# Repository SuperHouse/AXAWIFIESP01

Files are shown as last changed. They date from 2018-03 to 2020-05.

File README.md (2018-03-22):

AXA Electric Window Motor WiFi Controller (ESP-01)
===================================================
Copyright 2017 SuperHouse Automation Pty Ltd  www.superhouse.tv  

Add-in board for AXA domestic electric window mechanisms, to fit into
the battery compartment in place of the AA cells that are normally
installed. Uses an ESP8266 to connect to WiFi, and controls the AXA
window motor using LINbus.

More information is available on the project page at:

  http://www.superhouse.tv/axawifi

INSTALLATION
------------
The design is saved as an EAGLE project. EAGLE PCB design software is
available from www.cadsoftusa.com free for non-commercial use. To use
this project download it and place the directory containing these files
into the "eagle" directory on your computer. Then open EAGLE and
navigate to the projects listing.

DISTRIBUTION
------------
The specific terms of distribution of this project are governed by the
license referenced below.

LICENSE
-------
Licensed under the TAPR Open Hardware License (www.tapr.org/OHL).
The "license" folder within this repository also contains a copy of
this license in plain text format.

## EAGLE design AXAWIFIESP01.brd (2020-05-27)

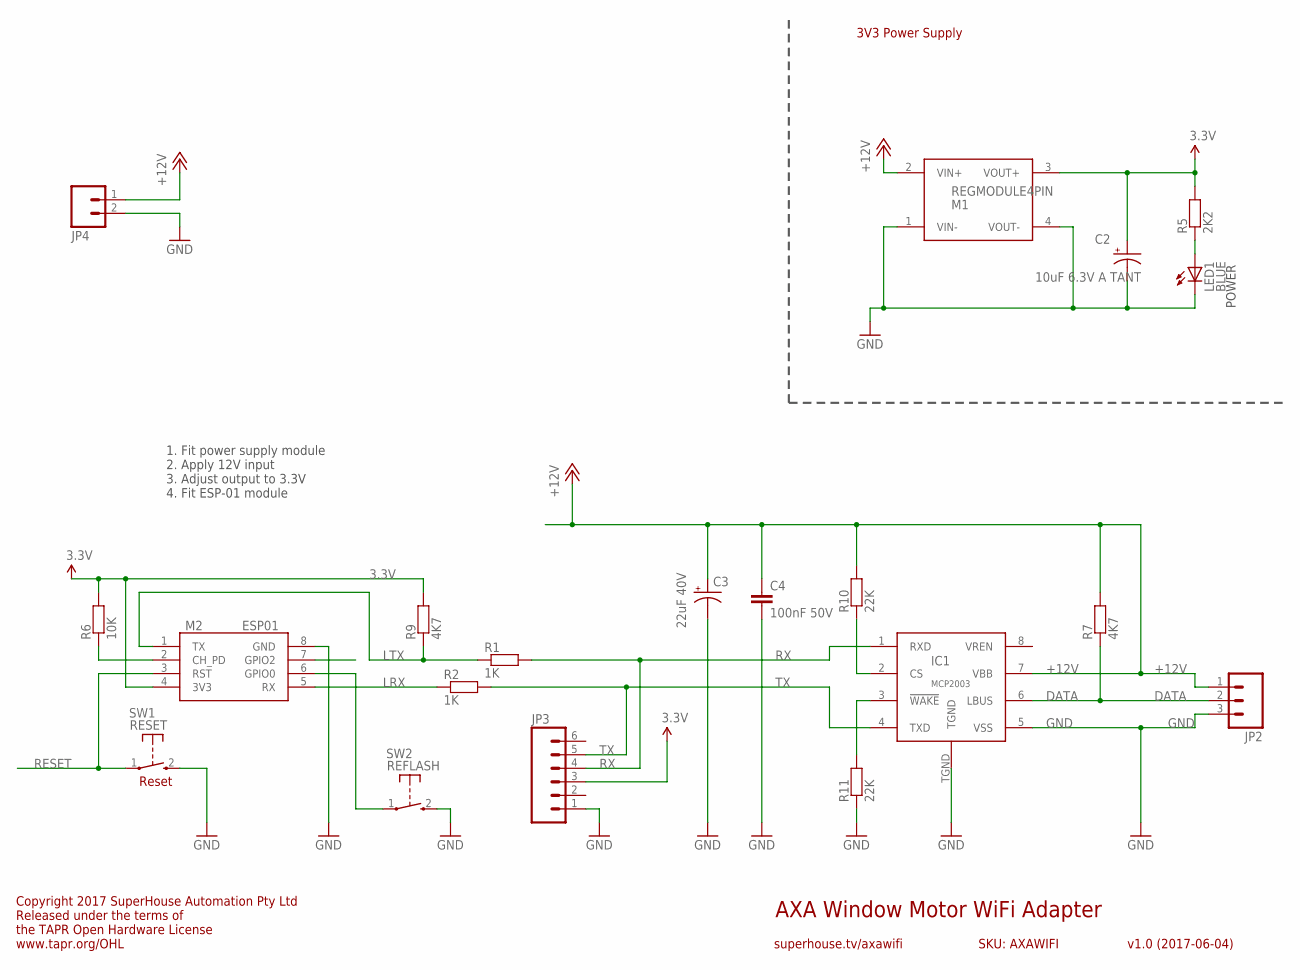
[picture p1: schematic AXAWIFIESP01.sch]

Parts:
C2: 10uF 6.3V A TANT; EIA3216
C3: 22uF 40V; PANASONIC_C
C4: 100nF 50V; C0603
IC1: MCP2003; SOIC8T
JP2: M03PTH; 1X03
JP3: M06SIP; 1X06
JP4: M02-SCREW-3.5MM; SCREWTERMINAL-3.5MM-2
LED1: BLUE; LED-0603
M1: REGMODULE4PIN
M2: ESP01
R1, R2: 1K; R0603
R5: 2K2; R0603
R6: 10K; R0603
R7, R9: 4K7; R0603
R10, R11: 22K; R0603
SW1: RESET; TACTILE_SMT_3X4X2
SW2: REFLASH; TACTILE_SMT_3X4X2

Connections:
3.3V: C2.A (+), JP3.3, M1.3 (VOUT+), M2.4 (3V3), R5.2, R6.2, R9.2
+12V: C3.+, C4.1, IC1.7 (VBB), JP2.1, JP4.1, M1.2 (VIN+), R7.2, R10.2
DATA: IC1.6 (LBUS), JP2.2, R7.1
GND: C2.C (-), C3.-, C4.2, IC1.5 (VSS), IC1.TGND, JP2.3, JP3.1, JP4.2, LED1.C, M1.1 (VIN-), M1.4 (VOUT-), M2.8 (GND), R11.1, SW1.2 (S), SW2.2 (S)
LRX: M2.5 (RX), R2.1
LTX: M2.1 (TX), R1.1, R9.1
unnamed: M2.6 (GPIO0), SW2.1
unnamed: M2.2 (CH_PD), R6.1
unnamed: IC1.2 (CS), R10.1
unnamed: IC1.3 (!WAKE), R11.2
unnamed: LED1.A, R5.1
RESET: M2.3 (RST), SW1.1
RX: IC1.1 (RXD), JP3.4, R1.2
TX: IC1.4 (TXD), JP3.5, R2.2

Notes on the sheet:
AXA Window Motor WiFi Adapter
v1.0 (2017-06-04)
superhouse.tv/axawifi
SKU: AXAWIFI
Reset
Copyright 2017 SuperHouse Automation Pty Ltd Released under the terms of the TAPR Open Hardware License www.tapr.org/OHL
POWER
3V3 Power Supply
1. Fit power supply module 2. Apply 12V input 3. Adjust output to 3.3V 4. Fit ESP-01 module

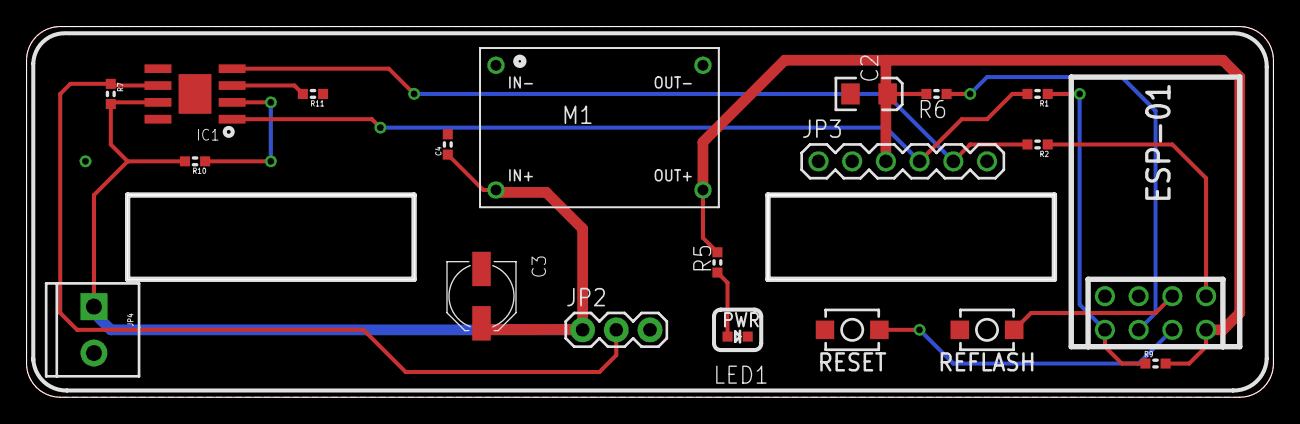
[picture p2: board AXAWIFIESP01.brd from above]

Board: 2 copper layers, 94.0 x 27.9 mm, 20 parts (0 on the bottom side), 14 nets.

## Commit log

2018-03-22 Initial project import from June 2017
    [AXAWIFIESP01.brd, AXAWIFIESP01.sch]
2020-05-27 Replace parts using SuperHouse library for 3D models
    [AXAWIFIESP01.brd, AXAWIFIESP01.sch]

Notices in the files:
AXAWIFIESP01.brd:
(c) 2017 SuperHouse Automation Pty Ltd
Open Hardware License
